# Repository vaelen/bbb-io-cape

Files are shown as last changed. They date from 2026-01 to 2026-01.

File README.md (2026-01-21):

# BeagleBone Black I/O Cape

A KiCad-designed I/O expansion cape for the BeagleBone Black SBC, featuring Grove-compatible connectors for easy interfacing with sensors, actuators, and communication peripherals.

**NOTE: The design has not yet been verified, use at your own risk!**

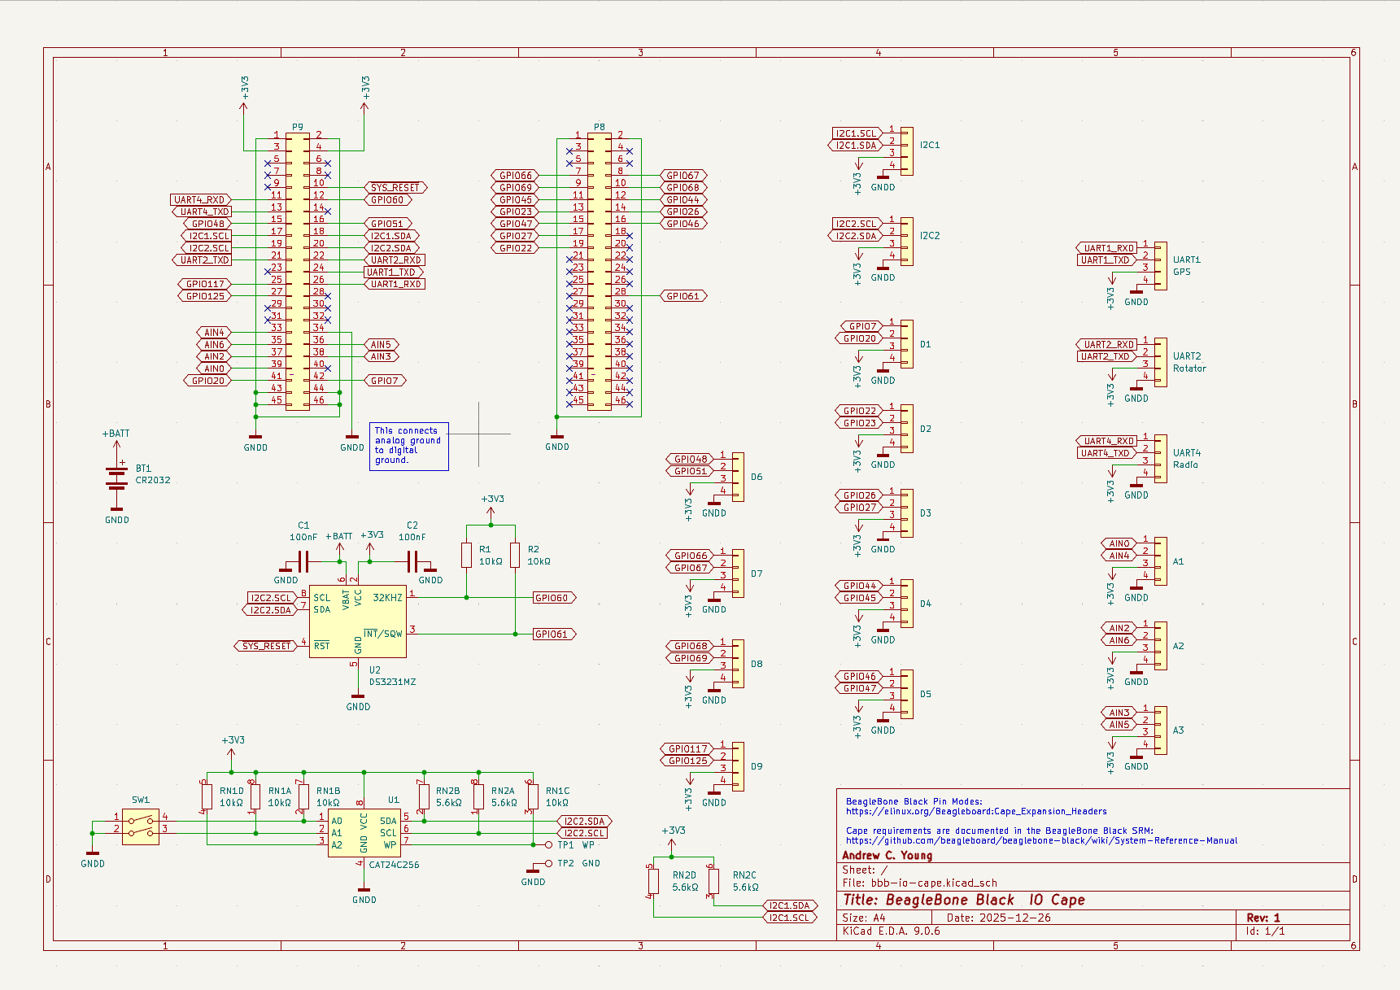
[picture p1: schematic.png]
schematic
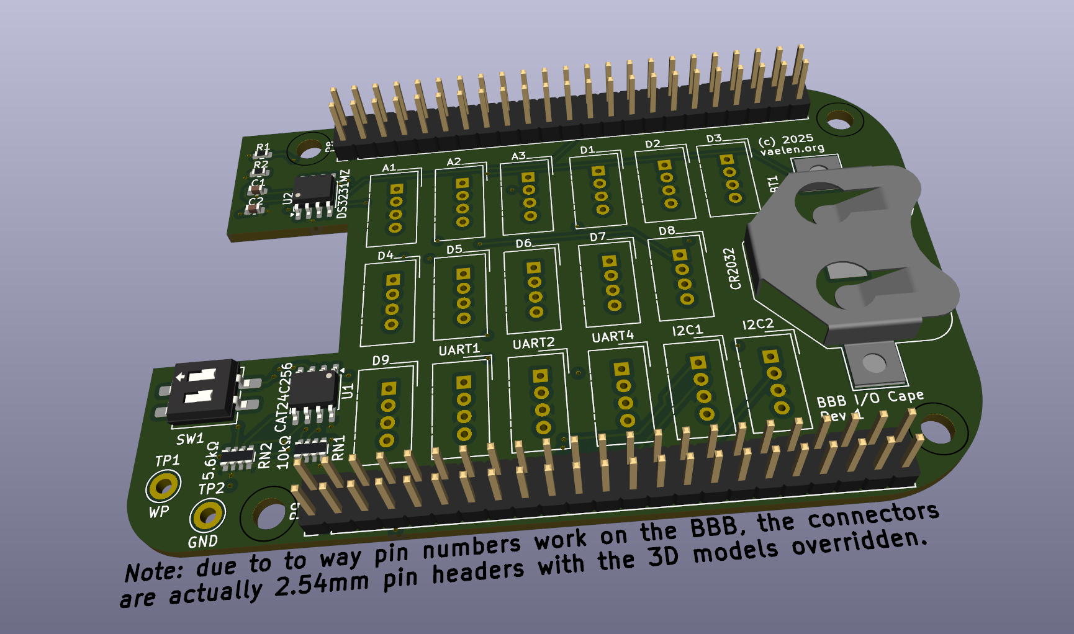
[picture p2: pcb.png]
PCB mockup
 

## Features

| Interface | Connector Count | Notes |
|---|---:|---|
| Analog | 3 | Grove 4-pin (A1, A2, A3) |
| Digital | 9 | Grove 4-pin (D1-D9) |
| I2C | 2 | Grove 4-pin (I2C1, I2C2) |
| UART | 3 | Grove 4-pin (UART1, UART2, UART4) |

### Onboard Components

- **DS3231MZ** - High-precision real-time clock with CR2032 battery backup
- **CAT24C256** - 256Kb I2C EEPROM for cape identification
- **2-position DIP switch** - Configuration options
- **Test points** - WP (write protect) and GND

## Pinout

The cape connects via the standard BeagleBone Black P8 and P9 expansion headers (2x23 pin, 2.54mm pitch).

### Connectors

| Connector | Pin 1 | Pin 2 | Function |
|---|---|---|---|
| UART1 | P9 / 26 | P9 / 24 | UART1 RX / TX |dtc -@ -I dts -O dtb -o BB-IO-CAPE-00A0.dtbo BB-IO-CAPE-00A0.dts
| UART2 | P9 / 22 | P9 / 21 | UART2 RX / TX |
| UART4 | P9 / 11 | P9 / 13 | UART4 RX / TX |
| I2C1 | P9 / 17 | P9 / 18 | I2C1 SCL / SDA |
| I2C2 | P9 / 19 | P9 / 20 | I2C2 SCL / SDA |
| A1 | P9 / 39 | P9 / 33 | AIN 0 / AIN 4 |
| A2 | P9 / 37 | P9 / 35 | AIN 2 / AIN 6 |
| A3 | P9 / 38 | P9 / 36 | AIN 3 / AIN 5 |
| D1 | P9 / 42 | P9 / 41 | GPIO 07 / GPIO 116  |
| D2 | P8 / 19 | P8 / 13 | GPIO 22 / GPIO 23 |
| D3 | P8 / 14 | P8 / 17 | GPIO 26 / GPIO 27 |
| D4 | P8 / 12 | P8 / 11 | GPIO 44 / GPIO 45 |
| D5 | P8 / 16 | P8 / 15 | GPIO 46 / GPIO 47 |
| D6 | P9 / 15 | P9 / 16 | GPIO 48 / GPIO 51 |
| D7 | P8 / 7  | P8 / 8  | GPIO 66 / GPIO 67 |
| D8 | P8 / 10 | P8 / 9  | GPIO 68 / GPIO 69 |
| D9 | P9 / 25 | P9 / 27 | GPIO 117 / GPIO 115 |
| RTC | P9 / 12 | P8 / 28 | GPIO 60 / GPIO 88 |

**Note:** All I/O signals are 3.3V. Do not apply 5V to any I/O pin.

## Real Time Clock

The real time clock is wired into the I2C2 bus as device 0x68.

## Device Tree Overlay

The cape includes a device tree overlay (`BB-IO-CAPE-00A0.dts`) that configures all peripherals for use under Linux.

The filename `BB-IO-CAPE-00A0` matches the part number (`BB-IO-CAPE`) and version (`00A0`) stored in the cape EEPROM, allowing U-Boot to automatically load the overlay at boot.

### Installing the Pre-compiled Overlay

A pre-compiled overlay (`BB-IO-CAPE-00A0.dtbo`) is included. To install on your BeagleBone:

```bash
# Copy the overlay to the firmware directory
sudo cp BB-IO-CAPE-00A0.dtbo /lib/firmware/
```

**Important:** The universal cape overlay and conflicting peripherals must be disabled to avoid pin conflicts. Edit `/boot/uEnv.txt` and make the following changes:

```bash
# Use the standard (non-universal) device tree
dtb=am335x-boneblack.dtb

# Comment out the universal cape enable
#enable_uboot_cape_universal=1

# Disable HDMI and audio (they conflict with GPIO pins)
disable_uboot_overlay_video=1
disable_uboot_overlay_audio=1
```

Then reboot for changes to take effect.

### Compiling from Source (Optional)

If you need to modify the overlay or compile it yourself:

```bash
# Preprocess and compile
cpp -nostdinc -I /usr/src/linux-headers-$(uname -r)/include \
    -undef -x assembler-with-cpp BB-IO-CAPE-00A0.dts | \
    dtc -@ -I dts -O dtb -o BB-IO-CAPE-00A0.dtbo -
```

### What the Overlay Configures

| Peripheral | Configuration |
|---|---|
| UART1 | P9.24 (TX), P9.26 (RX) - `/dev/ttyS1` |
| UART2 | P9.21 (TX), P9.22 (RX) - `/dev/ttyS2` |
| UART4 | P9.13 (TX), P9.11 (RX) - `/dev/ttyS4` |
| I2C1 | P9.17 (SCL), P9.18 (SDA) - `/dev/i2c-1` @ 400kHz  |
| I2C2 | P9.19 (SCL), P9.20 (SDA) - `/dev/i2c-2` @ 400kHz  |
| ADC | Channels 0, 2, 3, 4, 5, 6 enabled |
| DS3231 RTC | I2C2 @ 0x68 - `/dev/rtc1` |
| GPIO D1-D9 | 18 pins configured as outputs |
| RTC 32KHz  | GPIO 60 (P9.12) - 32KHz clock output |
| RTC Alarm  | GPIO 88 (P8.28) - Alarm interrupt (active low) |

### Verifying the Overlay

After loading the overlay, verify the devices are available:

```bash
# Check RTC
ls /dev/rtc*
hwclock -r -f /dev/rtc1

# Check I2C devices
i2cdetect -y -r 1   # I2C1 bus
i2cdetect -y -r 2   # I2C2 bus (should show RTC at 0x68)

# Check UARTs
ls /dev/ttyS*

# Check ADC values
cat /sys/bus/iio/devices/iio:device0/in_voltage0_raw
```

## Manufacturing

Production files (Gerbers, BOM, pick-and-place positions) can be generated using KiCad's fabrication toolkit or found in the `production/` directory.

### BOM Summary

| Component | Value/Part | Quantity |
|---|---|---|
| Grove 4-pin | Vertical | 17 |
| EEPROM | CAT24C256 | 1 |
| RTC | DS3231MZ | 1 |
| Battery | CR2032 | 1 |
| DIP Switch | 2-position | 1 |
| Capacitors | 100nF 0603 | 2 |
| Resistors | 10kΩ 0603 | 2 |
| Resistor Array| 10kΩ 4x0603  | 1 |
| Resistor Array| 5.6kΩ 4x0603 | 1 |

## Requirements

- KiCad 8.0 or later
- BeagleBone Black (or compatible: BBB Wireless, BeagleBone AI, etc.)

## License

MIT License

Copyright (c) 2026, Andrew C. Young

Permission is hereby granted, free of charge, to any person obtaining a copy
of this software and associated documentation files (the "Software"), to deal
in the Software without restriction, including without limitation the rights
to use, copy, modify, merge, publish, distribute, sublicense, and/or sell
copies of the Software, and to permit persons to whom the Software is
furnished to do so, subject to the following conditions:

The above copyright notice and this permission notice shall be included in all
copies or substantial portions of the Software.

THE SOFTWARE IS PROVIDED "AS IS", WITHOUT WARRANTY OF ANY KIND, EXPRESS OR
IMPLIED, INCLUDING BUT NOT LIMITED TO THE WARRANTIES OF MERCHANTABILITY,
FITNESS FOR A PARTICULAR PURPOSE AND NONINFRINGEMENT. IN NO EVENT SHALL THE
AUTHORS OR COPYRIGHT HOLDERS BE LIABLE FOR ANY CLAIM, DAMAGES OR OTHER
LIABILITY, WHETHER IN AN ACTION OF CONTRACT, TORT OR OTHERWISE, ARISING FROM,
OUT OF OR IN CONNECTION WITH THE SOFTWARE OR THE USE OR OTHER DEALINGS IN THE
SOFTWARE.

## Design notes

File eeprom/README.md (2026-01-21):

# BeagleBone Cape EEPROM Programming

This directory contains tools to program the identification EEPROM on the BB-IO-CAPE board.

## Overview

BeagleBone capes must have an EEPROM containing identification data so the BeagleBone can recognize and configure the cape during boot. The EEPROM stores:

- Board name and version
- Manufacturer information
- Serial number
- Pin configuration data
- Power requirements

## Hardware Setup

### EEPROM Details

| Parameter | Value |
|---|---|
| Chip | CAT24C256 (U1) |
| Capacity | 256 Kbit (32 KB) |
| I2C Bus | I2C-2 (P9 pins 19/20) |
| Write Protect | TP1 (ground to enable writes) |

### I2C Address Selection (SW1)

The DIP switch SW1 sets the EEPROM's I2C address:

| SW1 Position | A1  | A0  | I2C Address |
|---|-----|-----|---|
| All OFF | 1 | 1 | 0x57 |
| A0 ON | 1 | 0 | 0x56 |
| A1 ON | 0 | 1 | 0x55 |
| A0+A1 ON | 0 | 0 | 0x54 |

**Default:** All switches OFF = address 0x57

This allows up to 4 capes to be stacked, each with a unique address.

## Files

| File | Description |
|---|---|
| `generate_eeprom.py` | Python script to generate the EEPROM binary |
| `write_eeprom.sh` | Shell script to program EEPROM on BeagleBone |
| `cape_eeprom.bin` | Generated EEPROM binary image (after running py) |

## Usage

### Step 1: Generate the EEPROM Image

Run on any computer with Python 3:

```bash
# Generate with default settings
python3 generate_eeprom.py

# Generate with custom options
python3 generate_eeprom.py --serial 0125CAPE0001 -v

# See all options
python3 generate_eeprom.py --help
```

This creates `cape_eeprom.bin`.

### Step 2: Copy Files to BeagleBone

Copy both the binary and the write script to your BeagleBone:

```bash
scp cape_eeprom.bin write_eeprom.sh debian@beaglebone.local:~
```

### Step 3: Program the EEPROM

On the BeagleBone, with the cape attached:

```bash
sudo ./write_eeprom.sh cape_eeprom.bin
```

The script will:

1. Prompt you to ground TP1 (Write Protect)
2. Detect the EEPROM address automatically
3. Write the binary data to the EEPROM
4. Verify the write was successful
5. Prompt you to disconnect TP1

### Step 4: Verify Cape Detection

Reboot the BeagleBone and verify the cape is detected:

```bash
# Check cape manager slots
cat /sys/devices/platform/bone_capemgr/slots

# Check kernel messages
dmesg | grep -i cape

# Read EEPROM directly
hexdump -C /sys/bus/i2c/devices/2-0057/eeprom | head -10
```

## EEPROM Data Format

The EEPROM follows the BeagleBoard cape specification:

| Offset | Size | Field | Default Value |
|---|---|---|---|
| 0 | 4 | Magic Header | 0xAA5533EE |
| 4 | 2 | EEPROM Revision  | A1 |
| 6 | 32 | Board Name | BB-IO-CAPE |
| 38 | 4 | Version | 0001 |
| 42 | 16 | Manufacturer | Andrew C. Young |
| 58 | 16 | Part Number | BB-IO-CAPE-01 |
| 74 | 2 | Number of Pins | 0 |
| 76 | 12 | Serial Number | WWYYCAPE0001 |
| 88 | 148  | Pin Usage | (zeros) |
| 236 | 2 | VDD_3V3B Current | 50 mA |
| 238 | 2 | VDD_5V Current | 0 mA |
| 240 | 2 | SYS_5V Current | 0 mA |
| 242 | 2 | DC Supplied | 0 mA |

## Troubleshooting

### EEPROM not detected

1. Check that the cape is properly seated on the headers
2. Verify SW1 DIP switch position
3. Scan the I2C bus manually:

   ```bash
   sudo i2cdetect -y -r 2
   ```

   The EEPROM should appear at 0x54, 0x55, 0x56, or 0x57.

### Write fails / verification fails

1. Ensure TP1 is properly grounded to TP2
2. Check for loose connections
3. Try a slower write by modifying the dd block size in the script

### Cape not detected after reboot

1. Verify the magic header is correct: first 4 bytes should be `AA 55 33 EE`
2. Check that the board name starts with a valid prefix
3. Review `dmesg` for cape-related errors

## References

- [BeagleBoard Cape Support Documentation](https://docs.beagleboard.org/boards/beaglebone/black/ch08.html)
- [CAT24C256 Datasheet](https://www.onsemi.com/pdf/datasheet/cat24c256-d.pdf)
- [BBCape_EEPROM Tool](https://github.com/beagleboard/BBCape_EEPROM)

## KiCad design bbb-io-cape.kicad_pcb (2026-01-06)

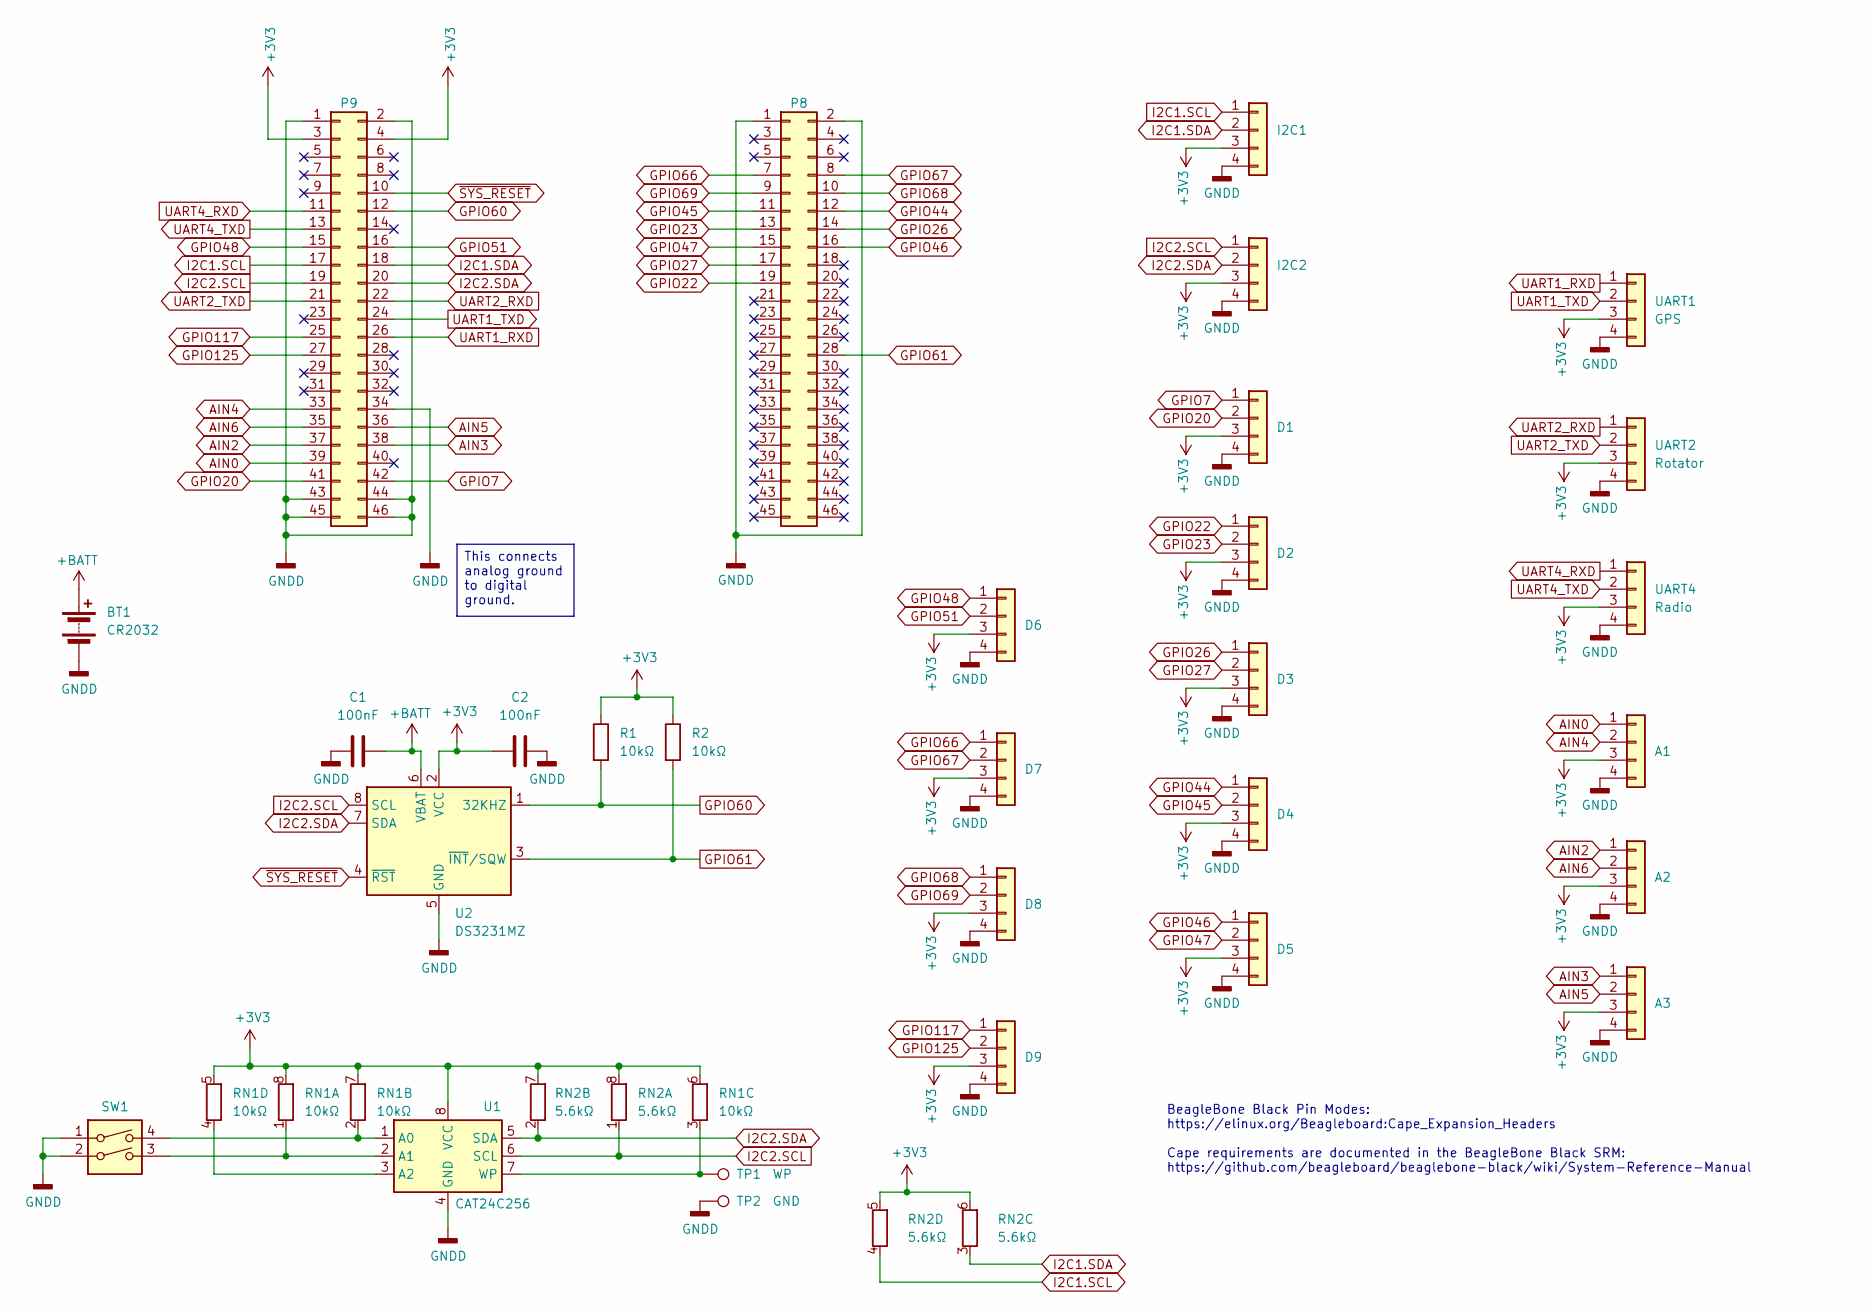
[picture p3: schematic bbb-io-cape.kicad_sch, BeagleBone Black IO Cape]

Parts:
A1, A2, A3: NS-Tech_Grove_1x04_P2mm_Vertical; LCSC Part # C5359601
BT1: CR2032; BatteryHolder_Multicomp_BC-2001_1x2032; LCSC Part # C964833
C1, C2: 100nF; C_0603_1608Metric; LCSC Part # C14663
D1, D2, D3, D4, D5, D6, D7, D8, D9: NS-Tech_Grove_1x04_P2mm_Vertical; LCSC Part # C5359601
I2C1, I2C2: NS-Tech_Grove_1x04_P2mm_Vertical; LCSC Part # C5359601
P8, P9: BeagleBone_Black_Header; PinHeader_2x23_P2.54mm_Vertical
R1, R2: 10kΩ; R_0603_1608Metric; LCSC Part # C25804
RN1: 10kΩ; R_Array_Convex_4x0603; LCSC Part # C29718
RN2: 5.6kΩ; R_Array_Convex_4x0603; LCSC Part # C12029
SW1: SW_DIP_x02; SW_DIP_SPSTx02_Slide_6.7x6.64mm_W8.61mm_P2.54mm_LowProfile; LCSC Part # C6331180
TP1: WP; TestPoint_Keystone_5010-5014_Multipurpose; LCSC Part # C2906765
TP2: GND; TestPoint_Keystone_5010-5014_Multipurpose; LCSC Part # C2906765
U1: CAT24C256; SOIC-8-1EP_3.9x4.9mm_P1.27mm_EP2.29x3mm; LCSC Part # C79987
U2: DS3231MZ; SOIC-8_3.9x4.9mm_P1.27mm; LCSC Part # C107410
UART1: GPS; NS-Tech_Grove_1x04_P2mm_Vertical; LCSC Part # C5359601
UART2: Rotator; NS-Tech_Grove_1x04_P2mm_Vertical; LCSC Part # C5359601
UART4: Radio; NS-Tech_Grove_1x04_P2mm_Vertical; LCSC Part # C5359601

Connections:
+3V3: A1.3, A2.3, A3.3, C2.2, D1.3, D2.3, D3.3, D4.3, D5.3, D6.3, D7.3, D8.3, D9.3, I2C1.3, I2C2.3, P9.3, P9.4, R1.1, R2.1, RN1.5 (R4.2), RN1.6 (R3.2), RN1.7 (R2.2), RN1.8 (R1.2), RN2.5 (R4.2), RN2.6 (R3.2), RN2.7 (R2.2), RN2.8 (R1.2), U1.8 (VCC), U2.2 (VCC), UART1.3, UART2.3, UART4.3
+BATT: BT1.1 (+), C1.2, U2.6 (VBAT)
AIN0: A1.1, P9.39
AIN2: A2.1, P9.37
AIN3: A3.1, P9.38
AIN4: A1.2, P9.33
AIN5: A3.2, P9.36
AIN6: A2.2, P9.35
GNDD: A1.4, A2.4, A3.4, BT1.2 (-), C1.1, C2.1, D1.4, D2.4, D3.4, D4.4, D5.4, D6.4, D7.4, D8.4, D9.4, I2C1.4, I2C2.4, P8.1, P8.2, P9.1, P9.2, P9.34, P9.43, P9.44, P9.45, P9.46, SW1.1, SW1.2, TP2.1, U1.4 (GND), U2.5 (GND), UART1.4, UART2.4, UART4.4
GPIO7: D1.1, P9.42
GPIO20: D1.2, P9.41
GPIO22: D2.1, P8.19
GPIO23: D2.2, P8.13
GPIO26: D3.1, P8.14
GPIO27: D3.2, P8.17
GPIO44: D4.1, P8.12
GPIO45: D4.2, P8.11
GPIO46: D5.1, P8.16
GPIO47: D5.2, P8.15
GPIO48: D6.1, P9.15
GPIO51: D6.2, P9.16
GPIO60: P9.12, R1.2, U2.1 (32KHZ)
GPIO61: P8.28, R2.2, U2.3 (~INT/SQW)
GPIO66: D7.1, P8.7
GPIO67: D7.2, P8.8
GPIO68: D8.1, P8.10
GPIO69: D8.2, P8.9
GPIO117: D9.1, P9.25
GPIO125: D9.2, P9.27
I2C1.SCL: I2C1.1, P9.17, RN2.4 (R4.1)
I2C1.SDA: I2C1.2, P9.18, RN2.3 (R3.1)
I2C2.SCL: I2C2.1, P9.19, RN2.1 (R1.1), U1.6 (SCL), U2.8 (SCL)
I2C2.SDA: I2C2.2, P9.20, RN2.2 (R2.1), U1.5 (SDA), U2.7 (SDA)
unnamed: RN1.1 (R1.1), SW1.3, U1.2 (A1)
unnamed: RN1.2 (R2.1), SW1.4, U1.1 (A0)
unnamed: RN1.3 (R3.1), TP1.1, U1.7 (WP)
unnamed: RN1.4 (R4.1), U1.3 (A2)
UART1_RXD: P9.26, UART1.1
UART1_TXD: P9.24, UART1.2
UART2_RXD: P9.22, UART2.1
UART2_TXD: P9.21, UART2.2
UART4_RXD: P9.11, UART4.1
UART4_TXD: P9.13, UART4.2
~SYS_RESET: P9.10, U2.4 (~RST)

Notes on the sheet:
BeagleBone Black Pin Modes: https://elinux.org/Beagleboard:Cape_Expansion_Headers Cape requirements are documented in the BeagleBone Black SRM: https://github.com/beagleboard/beaglebone-black/wiki/System-Reference-Manual
This connects analog ground to digital ground.

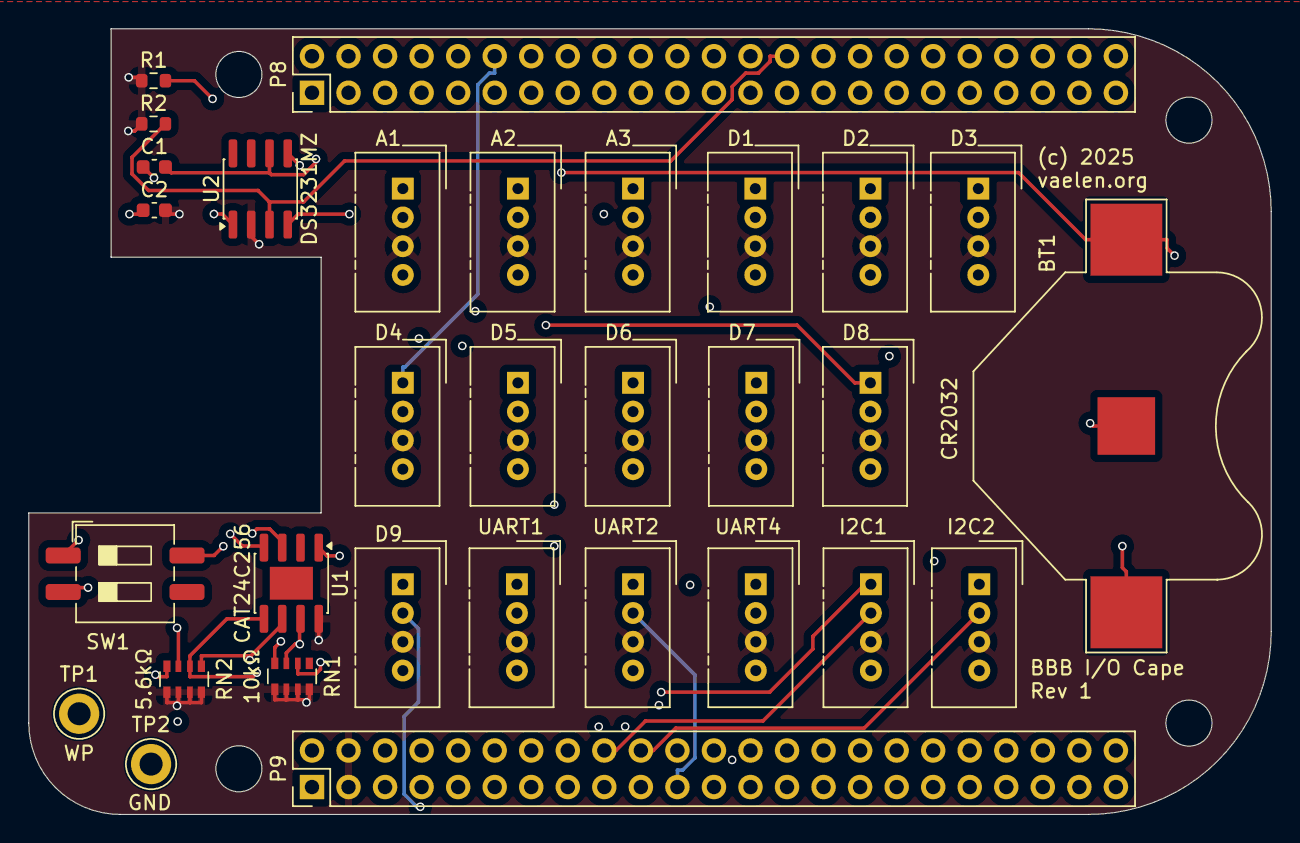
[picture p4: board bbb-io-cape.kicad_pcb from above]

Board: 4 copper layers, 86.4 x 54.6 mm, 35 parts (0 on the bottom side), 44 nets.

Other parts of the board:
MH1, MH2, MH3, MH4: MountingHole_3.2mm_M3_DIN965

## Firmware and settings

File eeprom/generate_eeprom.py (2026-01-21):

#!/usr/bin/env python3
"""
BeagleBone Black Cape EEPROM Generator

Generates a binary EEPROM image following the BeagleBoard cape specification.
See: https://docs.beagleboard.org/boards/beaglebone/black/ch08.html
"""

import argparse
import struct
import datetime
import sys
from pathlib import Path

# EEPROM field sizes (bytes)
HEADER_SIZE = 4
EEPROM_REV_SIZE = 2
BOARD_NAME_SIZE = 32
VERSION_SIZE = 4
MANUFACTURER_SIZE = 16
PART_NUMBER_SIZE = 16
NUM_PINS_SIZE = 2
SERIAL_NUMBER_SIZE = 12
PIN_USAGE_SIZE = 148  # 74 pins * 2 bytes each
VDD_3V3B_SIZE = 2
VDD_5V_SIZE = 2
SYS_5V_SIZE = 2
DC_SUPPLIED_SIZE = 2

# Magic header bytes
EEPROM_HEADER = bytes([0xAA, 0x55, 0x33, 0xEE])

# Default values for BB-IO-CAPE
# Note: U-Boot constructs overlay filename as {part_number}-{version}.dtbo
# Part number should not have trailing spaces/nulls that could corrupt the filename
DEFAULTS = {
    'board_name': 'BB-IO-CAPE',
    'version': '00A0',
    'manufacturer': 'Andrew C. Young',
    'part_number': 'BB-IO-CAPE',       # Results in BB-IO-CAPE-00A0.dtbo
    'eeprom_rev': 'A1',
    'vdd_3v3b_ma': 50,   # Estimated current draw in mA
    'vdd_5v_ma': 0,      # Not using 5V rail
    'sys_5v_ma': 0,      # Not using SYS_5V
    'dc_supplied_ma': 0, # Not supplying power
}


def pad_string(s: str, length: int, pad_char: bytes = b'\x00') -> bytes:
    """Pad a string with null bytes to the specified length.

    Using null padding instead of space padding ensures U-Boot correctly
    identifies the end of the string when constructing overlay filenames.
    """
    encoded = s.encode('ascii')
    if len(encoded) > length:
        raise ValueError(f"String '{s}' exceeds maximum length of {length}")
    return encoded.ljust(length, pad_char)


def generate_serial_number(assembly_code: str = 'CAPE') -> str:
    """
    Generate a serial number in the format WWYY&&&&nnnn.

    WW: Week of production (01-52)
    YY: Year of production (last two digits)
    &&&&: Assembly code (4 chars)
    nnnn: Board number (0001-9999)
    """
    now = datetime.datetime.now()
    week = now.isocalendar()[1]
    year = now.year % 100
    # Pad or truncate assembly code to 4 characters
    assembly = assembly_code[:4].ljust(4, '0')
    return f"{week:02d}{year:02d}{assembly}0001"

def build_pin_usage_data() -> bytes:
    """
    Build the pin usage data for the BB-IO-CAPE.

    Each pin is represented by 2 bytes (16 bits) in Big Endian:
    - Bit 15: Pin used (1) or not used (0)
    - Bits 14-7: Reserved (0)
    - Bit 6: Slew rate (0=fast, 1=slow)
    - Bit 5: RX enable (0=disabled, 1=enabled)
    - Bit 4: Pull up/down select (0=pulldown, 1=pullup)
    - Bit 3: Pull up/down enable (0=enabled, 1=disabled)
    - Bits 2-0: Mux mode (0-7)

    Pin index mapping:
    - P8 pins 1-46 -> indices 0-45
    - P9 pins 1-46 -> indices 46-91
    """
    # Initialize all 74 pins as unused (74 pins * 2 bytes = 148 bytes)
    pin_data = bytearray(PIN_USAGE_SIZE)

    def set_pin(header: int, pin: int, mux_mode: int = 7,
                rx_enable: bool = False, pullup: bool = True,
                pull_disable: bool = False, slew_slow: bool = False):
        """Set a pin as used with the specified configuration."""
        # Calculate index: P8 pins are 0-45, P9 pins are 46-91
        if header == 8:
            index = pin - 1
        else:  # header == 9
            index = 46 + (pin - 1)

        if index < 0 or index >= 74:
            return  # Skip invalid indices

        # Build the 16-bit value
        value = 0x8000  # Bit 15: pin used
        if slew_slow:
            value |= 0x0040  # Bit 6
        if rx_enable:
            value |= 0x0020  # Bit 5
        if pullup:
            value |= 0x0010  # Bit 4
        if pull_disable:
            value |= 0x0008  # Bit 3
        value |= (mux_mode & 0x07)  # Bits 2-0

        # Store as Big Endian
        pin_data[index * 2] = (value >> 8) & 0xFF
        pin_data[index * 2 + 1] = value & 0xFF

    # BB-IO-CAPE Pin Configuration (from README.md)
    #
    # UART1: P9/26 (RX), P9/24 (TX) - Mode 0
    set_pin(9, 26, mux_mode=0, rx_enable=True)   # UART1_RXD
    set_pin(9, 24, mux_mode=0)                    # UART1_TXD

    # UART2: P9/22 (RX), P9/21 (TX) - Mode 1
    set_pin(9, 22, mux_mode=1, rx_enable=True)   # UART2_RXD
    set_pin(9, 21, mux_mode=1)                    # UART2_TXD

    # UART4: P9/11 (RX), P9/13 (TX) - Mode 6
    set_pin(9, 11, mux_mode=6, rx_enable=True)   # UART4_RXD
    set_pin(9, 13, mux_mode=6)                    # UART4_TXD

    # I2C1: P9/17 (SCL), P9/18 (SDA) - Mode 2
    set_pin(9, 17, mux_mode=2, rx_enable=True)   # I2C1_SCL
    set_pin(9, 18, mux_mode=2, rx_enable=True)   # I2C1_SDA

    # I2C2: P9/19 (SCL), P9/20 (SDA) - Mode 3
    # Note: I2C2 is used for cape EEPROM, directly connected
    set_pin(9, 19, mux_mode=3, rx_enable=True)   # I2C2_SCL
    set_pin(9, 20, mux_mode=3, rx_enable=True)   # I2C2_SDA

    # Analog inputs (A1, A2, A3) - these only use bit 15 (used flag)
    # A1: P9/39 (AIN0), P9/33 (AIN4)
    set_pin(9, 39, mux_mode=0)  # AIN0
    set_pin(9, 33, mux_mode=0)  # AIN4
    # A2: P9/37 (AIN2), P9/35 (AIN6)
    set_pin(9, 37, mux_mode=0)  # AIN2
    set_pin(9, 35, mux_mode=0)  # AIN6
    # A3: P9/38 (AIN3), P9/36 (AIN5)
    set_pin(9, 38, mux_mode=0)  # AIN3
    set_pin(9, 36, mux_mode=0)  # AIN5

    # Digital GPIO connectors (D1-D9) - Mode 7 (GPIO)
    # D1: P9/42 (GPIO 07), P9/41 (GPIO 116)
    set_pin(9, 42, mux_mode=7)
    set_pin(9, 41, mux_mode=7)
    # D2: P8/19 (GPIO 22), P8/13 (GPIO 23)
    set_pin(8, 19, mux_mode=7)
    set_pin(8, 13, mux_mode=7)
    # D3: P8/14 (GPIO 26), P8/17 (GPIO 27)
    set_pin(8, 14, mux_mode=7)
    set_pin(8, 17, mux_mode=7)
    # D4: P8/12 (GPIO 44), P8/11 (GPIO 45)
    set_pin(8, 12, mux_mode=7)
    set_pin(8, 11, mux_mode=7)
    # D5: P8/16 (GPIO 46), P8/15 (GPIO 47)
    set_pin(8, 16, mux_mode=7)
    set_pin(8, 15, mux_mode=7)
    # D6: P9/15 (GPIO 48), P9/16 (GPIO 51)
    set_pin(9, 15, mux_mode=7)
    set_pin(9, 16, mux_mode=7)
    # D7: P8/7 (GPIO 66), P8/8 (GPIO 67)
    set_pin(8, 7, mux_mode=7)
    set_pin(8, 8, mux_mode=7)
    # D8: P8/10 (GPIO 68), P8/9 (GPIO 69)
    set_pin(8, 10, mux_mode=7)
    set_pin(8, 9, mux_mode=7)
    # D9: P9/25 (GPIO 117), P9/27 (GPIO 115)
    set_pin(9, 25, mux_mode=7)
    set_pin(9, 27, mux_mode=7)

    # RTC: P9/12 (GPIO 60), P8/28 (GPIO 88) - for RTC interrupt/output
    set_pin(9, 12, mux_mode=7)
    set_pin(8, 28, mux_mode=7)

    return bytes(pin_data)


def generate_eeprom(args) -> bytes:
    """Generate the complete EEPROM binary image."""
    data = bytearray()

    # Header (4 bytes) - Magic number
    data.extend(EEPROM_HEADER)

    # EEPROM Revision (2 bytes)
    data.extend(pad_string(args.eeprom_rev, EEPROM_REV_SIZE))

    # Board Name (32 bytes)
    data.extend(pad_string(args.board_name, BOARD_NAME_SIZE))

    # Version (4 bytes)
    data.extend(pad_string(args.version, VERSION_SIZE))

    # Manufacturer (16 bytes)
    data.extend(pad_string(args.manufacturer, MANUFACTURER_SIZE))

    # Part Number (16 bytes)
    data.extend(pad_string(args.part_number, PART_NUMBER_SIZE))

    # Number of Pins (2 bytes) - Big Endian
    # Count: 3 UARTs (6 pins) + 2 I2C (4 pins) + 3 Analog (6 pins)
    #      + 9 Digital (18 pins) + 1 RTC (2 pins) = 36 pins
    num_pins = 36
    data.extend(struct.pack('>H', num_pins))

    # Serial Number (12 bytes)
    serial = args.serial or generate_serial_number()
    data.extend(pad_string(serial, SERIAL_NUMBER_SIZE))

    # Pin Usage (148 bytes)
    data.extend(build_pin_usage_data())

    # VDD_3V3B Current (2 bytes) - Big Endian, in mA
    data.extend(struct.pack('>H', args.vdd_3v3b_ma))

    # VDD_5V Current (2 bytes) - Big Endian, in mA
    data.extend(struct.pack('>H', args.vdd_5v_ma))

    # SYS_5V Current (2 bytes) - Big Endian, in mA
    data.extend(struct.pack('>H', args.sys_5v_ma))

    # DC Supplied (2 bytes) - Big Endian, in mA
    data.extend(struct.pack('>H', args.dc_supplied_ma))

    return bytes(data)


def print_eeprom_info(data: bytes):
    """Print a human-readable summary of the EEPROM contents."""
    print("\nEEPROM Contents:")
    print("-" * 50)
    print(f"Header:       0x{data[0:4].hex().upper()}")
    print(f"EEPROM Rev:   {data[4:6].decode('ascii').strip()}")
    print(f"Board Name:   {data[6:38].decode('ascii').strip()}")
    print(f"Version:      {data[38:42].decode('ascii').strip()}")
    print(f"Manufacturer: {data[42:58].decode('ascii').strip()}")
    print(f"Part Number:  {data[58:74].decode('ascii').strip()}")
    print(f"Num Pins:     {struct.unpack('>H', data[74:76])[0]}")
    print(f"Serial:       {data[76:88].decode('ascii').strip()}")
    print(f"VDD_3V3B:     {struct.unpack('>H', data[236:238])[0]} mA")
    print(f"VDD_5V:       {struct.unpack('>H', data[238:240])[0]} mA")
    print(f"SYS_5V:       {struct.unpack('>H', data[240:242])[0]} mA")
    print(f"DC Supplied:  {struct.unpack('>H', data[242:244])[0]} mA")
    print(f"Total size:   {len(data)} bytes")
    print("-" * 50)


def main():
    parser = argparse.ArgumentParser(
        description='Generate BeagleBone Cape EEPROM binary image',
        formatter_class=argparse.RawDescriptionHelpFormatter,
        epilog="""
Examples:
  %(prog)s                          # Generate with defaults
  %(prog)s -o my_cape.bin           # Specify output file
  %(prog)s --serial 0325CAPE0042    # Specify serial number
        """
    )

    parser.add_argument('-o', '--output', type=str, default='cape_eeprom.bin',
                        help='Output filename (default: cape_eeprom.bin)')
    parser.add_argument('--board-name', type=str, default=DEFAULTS['board_name'],
                        help=f"Board name, max 32 chars (default: {DEFAULTS['board_name']})")
    parser.add_argument('--version', type=str, default=DEFAULTS['version'],
                        help=f"Hardware version, 4 chars (default: {DEFAULTS['version']})")
    parser.add_argument('--manufacturer', type=str, default=DEFAULTS['manufacturer'],
                        help=f"Manufacturer name, max 16 chars (default: {DEFAULTS['manufacturer']})")
    parser.add_argument('--part-number', type=str, default=DEFAULTS['part_number'],
                        help=f"Part number, max 16 chars (default: {DEFAULTS['part_number']})")
    parser.add_argument('--eeprom-rev', type=str, default=DEFAULTS['eeprom_rev'],
                        help=f"EEPROM revision, 2 chars (default: {DEFAULTS['eeprom_rev']})")
    parser.add_argument('--serial', type=str, default=None,
                        help='Serial number, 12 chars (default: auto-generated)')
    parser.add_argument('--vdd-3v3b-ma', type=int, default=DEFAULTS['vdd_3v3b_ma'],
                        help=f"VDD_3V3B current in mA (default: {DEFAULTS['vdd_3v3b_ma']})")
    parser.add_argument('--vdd-5v-ma', type=int, default=DEFAULTS['vdd_5v_ma'],
                        help=f"VDD_5V current in mA (default: {DEFAULTS['vdd_5v_ma']})")
    parser.add_argument('--sys-5v-ma', type=int, default=DEFAULTS['sys_5v_ma'],
                        help=f"SYS_5V current in mA (default: {DEFAULTS['sys_5v_ma']})")
    parser.add_argument('--dc-supplied-ma', type=int, default=DEFAULTS['dc_supplied_ma'],
                        help=f"DC supplied current in mA (default: {DEFAULTS['dc_supplied_ma']})")
    parser.add_argument('-v', '--verbose', action='store_true',
                        help='Print EEPROM contents after generation')

    args = parser.parse_args()

    # Generate the EEPROM data
    eeprom_data = generate_eeprom(args)

    # Write to file
    output_path = Path(args.output)
    output_path.write_bytes(eeprom_data)
    print(f"Generated EEPROM image: {output_path} ({len(eeprom_data)} bytes)")

    if args.verbose:
        print_eeprom_info(eeprom_data)

    # Always print a hex dump of the first 96 bytes (the identification data)
    print("\nFirst 96 bytes (hex):")
    for i in range(0, min(96, len(eeprom_data)), 16):
        hex_part = ' '.join(f'{b:02X}' for b in eeprom_data[i:i+16])
        ascii_part = ''.join(chr(b) if 32 <= b < 127 else '.' for b in eeprom_data[i:i+16])
        print(f"  {i:04X}: {hex_part:<48} |{ascii_part}|")


if __name__ == '__main__':
    main()

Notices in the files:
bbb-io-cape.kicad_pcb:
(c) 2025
